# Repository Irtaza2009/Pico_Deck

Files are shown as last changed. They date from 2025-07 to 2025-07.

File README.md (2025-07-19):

# Pico Deck + USB Rubber Ducky 

### **A flash-drive-sized USB macropad and rubber ducky!**  



A small **flash-drive** but with *__buttonnnnsssss for shortcuts__* instead of storage!! And with a _custom **rp2040** devboard!_
And _**LEDDDsss!**_
And it can _run different scripts_ on the computer it's plugged into, like a **USB rubber ducky**!

I created this to learn how to make a devboard, how hard it is, and what modifications can be applied to it!

## Preview

| Description | Image |
|---|---|
| Schematic | 
| PCB Top Layer |  
| PCB Bottom Layer | 
| PCB 3D Render Front |  
| PCB 3D Render Back | 
| 3D Case + PCB | 

## BOM

| Component Description | Quantity | LCSC Part # | Price (USD) | LCSC Link |
|---|---|---|---|---|
| Tactile Switch SKRPACE010 | 1 | C139797 | 0.60 | [Link](https://lcsc.com/product-detail/Tactile-Switches_ALPSALPINE-SKRPACE010_C139797.html?s_z=n_C139797) |
| 100nF Ceramic Capacitor | 20 | C14663 | 0.24 | [Link](https://lcsc.com/product-detail/Multilayer-Ceramic-Capacitors-MLCC-SMD-SMT_YAGEO-CC0603KRX7R9BB104_C14663.html) |
| 10uF Ceramic Capacitor | 2 | C19702 | 0.30 | [Link](https://lcsc.com/product-detail/Multilayer-Ceramic-Capacitors-MLCC-SMD-SMT_Samsung-Electro-Mechanics-CL10A106KP8NNNC_C19702.html) |
| 14pF Ceramic Capacitor | 2 | C5360816 | 0.30 | [Link](https://lcsc.com/product-detail/Multilayer-Ceramic-Capacitors-MLCC-SMD-SMT_CCTC-TCC0603COG140J500CT_C5360816.html) |
| WS2812B RGB LED (2020) | 8 | C965555 | 4.00 | [Link](https://lcsc.com/product-detail/RGB-LEDs-Built-in-IC_Worldsemi-WS2812B-2020_C965555.html) |
| 27Ω Resistor | 2 | C137753 | 0.12 | [Link](https://lcsc.com/product-detail/Chip-Resistor-Surface-Mount_YAGEO-RC0603FR-0727RL_C137753.html) |
| 10kΩ Resistor | 2 | C98220 | 0.11 | [Link](https://lcsc.com/product-detail/Chip-Resistor-Surface-Mount_YAGEO-RC0603FR-0710KL_C98220.html) |
| 1kΩ Resistor | 1 | C22548 | 0.11 | [Link](https://lcsc.com/product-detail/Chip-Resistor-Surface-Mount_YAGEO-RC0603FR-071KL_C22548.html) |
| Tactile Switch B3U-1000P | 1 | C231329 | 2.00 | [Link](https://lcsc.com/product-detail/Tactile-Switches_OMRON-B3U-1000P_C231329.html) |
| Tactile Switch TS-1002S-05026C | 4 | C455110 | 1.00 | [Link](https://lcsc.com/product-detail/Tactile-Switches_XUNPU-TS-1002S-05026C_C455110.html) |
| 4-pin Header B-2100S04P-A110 | 1 | C124378 | 0.41 | [Link](https://lcsc.com/product-detail/Pin-Headers_Ckmtw-Shenzhen-Cankemeng-B-2100S04P-A110_C124378.html) |
| RP2040 Microcontroller | 1 | C2040 | 6.00 | [Link](https://lcsc.com/product-detail/Microcontrollers-MCU-MPU-SOC_Raspberry-Pi-RP2040_C2040.html) |
| LDO Regulator AP2112K-3.3TRG1 | 1 | C51118 | 1.00 | [Link](https://lcsc.com/product-detail/Voltage-Regulators-Linear-Low-Drop-Out-LDO-Regulators_DIODES-AP2112K-3-3TRG1_C51118.html) |
| Flash Memory W25Q128JWPIQ | 1 | C2689660 | 5.80 | [Link](https://lcsc.com/product-detail/NOR-FLASH_Winbond-W25Q128JWPIQ_C2689660.html) |
| USB-A Port AM90 | 1 | C404965 | 0.62 | [Link](https://lcsc.com/product-detail/USB-Connectors_SHOU-HAN-AM90_C404965.html) |
| 12MHz Crystal TAXM12M4RFBCCT2T | 1 | C133337 | 0.51 | [Link](https://lcsc.com/product-detail/Crystals_Yajingxin-TAXM12M4RFBCCT2T_C133337.html) |
| PCB | 5 | JLCPCB | 2.00 | N/A |
| PCBA | 5 | JLCPCB | 130.00 | N/A |
| Shipping | 5 | JLCPCB | 32.00 | N/A |

**PCBA is expensive:**



Subtotal (excluding PCBA): US$25

Estimated cost (PCBA, including parts and PCB): US$150 (with a coupon!)

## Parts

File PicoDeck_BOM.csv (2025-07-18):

No. | Quantity | Comment | Designator | Footprint | Value | Manufacturer Part | Manufacturer | Supplier Part | Supplier | Price ($) | Link
1 | 1 | SKRPACE010 | BOOT | KEY-SMD_4P-L4.2-W3.2-P2.20-LS4.6 |  | SKRPACE010 | ALPSALPINE(阿尔卑斯阿尔派) | C139797 | LCSC | 0.6 | https://lcsc.com/product-detail/Tactile-Switches_ALPSALPINE-SKRPACE010_C139797.html?s_z=n_C139797
2 | 20 | 100nF | C1,C2,C3,C4,C5,C6,C7,C8,C9,C10,C11,C14,C15,C16,C17,C18,C19,C20,C21,C22 | C0603 | 100nF | CC0603KRX7R9BB104 | YAGEO(国巨) | C14663 | LCSC | 0.24 | https://lcsc.com/product-detail/Multilayer-Ceramic-Capacitors-MLCC-SMD-SMT_YAGEO-CC0603KRX7R9BB104_C14663.html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
3 | 2 | 10uF | C12,C13 | C0603 | 10uF | CL10A106KP8NNNC | SAMSUNG(三星) | C19702 | LCSC | 0.3 | https://lcsc.com/product-detail/Multilayer-Ceramic-Capacitors-MLCC-SMD-SMT_Samsung-Electro-Mechanics-CL10A106KP8NNNC_C19702.html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
4 | 2 | 14pF | C23,C24 | C0603 | 14pF | TCC0603COG140J500CT | CCTC(三环) | C5360816 | LCSC | 0.3 | https://lcsc.com/product-detail/Multilayer-Ceramic-Capacitors-MLCC-SMD-SMT_CCTC-TCC0603COG140J500CT_C5360816.html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
5 | 8 | WS2812B-2020 | LED1,LED2,LED3,LED4,LED5,LED6,LED7,LED8 | LED-SMD_4P-L2.0-W2.0-TL_WS2812B-2020 |  | WS2812B-2020 | worldsemi | C965555 | LCSC | 4.0 | https://lcsc.com/product-detail/RGB-LEDs-Built-in-IC_Worldsemi-WS2812B-2020_C965555.html?s_z=n_C965555
6 | 2 | 27Ω | R1,R2 | R0603 | 27Ω | RC0603FR-0727RL | YAGEO(国巨) | C137753 | LCSC | 0.12 | https://lcsc.com/product-detail/Chip-Resistor-Surface-Mount_YAGEO-RC0603FR-0727RL_C137753.html?s_z=n_C137753
7 | 2 | 10kΩ | R3,R5 | R0603 | 10kΩ | RC0603FR-0710KL | YAGEO(国巨) | C98220 | LCSC | 0.11 | https://lcsc.com/product-detail/Chip-Resistor-Surface-Mount_YAGEO-RC0603FR-0710KL_C98220.html?s_z=n_C98220
8 | 1 | 1kΩ | R4 | R0603 | 1kΩ | RC0603FR-071KL | YAGEO(国巨) | C22548 | LCSC | 0.11 | https://lcsc.com/product-detail/Chip-Resistor-Surface-Mount_YAGEO-RC0603FR-071KL_C22548.html?s_z=n_C22548
9 | 1 | B3U-1000P | RESET_KEY1 | KEY-SMD_B3U-1000PM |  | B3U-1000P | OMRON(欧姆龙) | C231329 | LCSC | 2.0 | https://lcsc.com/product-detail/Tactile-Switches_OMRON-B3U-1000P_C231329.html?s_z=n_B3U-1000P%2509
10 | 4 | TS-1002S-05026C | SW1,SW2,SW3,SW4 | KEY-SMD_4P-L6.0-W6.0-P4.50-LS9.0 |  | TS-1002S-05026C | XUNPU(讯普) | C455110 | LCSC | 1.0 | https://lcsc.com/product-detail/Tactile-Switches_XUNPU-TS-1002S-05026C_C455110.html?s_z=n_C455110
11 | 1 | B-2100S04P-A110 | SWD1 | HDR-TH_4P-P2.54-V-M |  | B-2100S04P-A110 | Ckmtw(灿科盟) | C124378 | LCSC | 0.41 | https://lcsc.com/product-detail/Pin-Headers_Ckmtw-Shenzhen-Cankemeng-B-2100S04P-A110_C124378.html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
12 | 1 | RP2040 | U1 | LQFN-56_L7.0-W7.0-P0.4-EP |  | RP2040 | Raspberry Pi(树莓派) | C2040 | LCSC | 6.0 | https://lcsc.com/product-detail/Microcontrollers-MCU-MPU-SOC_Raspberry-Pi-RP2040_C2040.html?s_z=n_C2040
13 | 1 | AP2112K-3.3TRG1 | U6 | SOT-25-5_L2.9-W1.6-P0.95-LS2.8-BL |  | AP2112K-3.3TRG1 | DIODES(美台) | C51118 | LCSC | 1.0 | https://lcsc.com/product-detail/Voltage-Regulators-Linear-Low-Drop-Out-LDO-Regulators_DIODES-AP2112K-3-3TRG1_C51118.html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
14 | 1 | W25Q128JWPIQ | U7 | WSON-8_L6.0-W5.0-P1.27-BL-EP |  | W25Q128JWPIQ | Winbond(华邦) | C2689660 | LCSC | 5.8 | https://lcsc.com/product-detail/NOR-FLASH_Winbond-W25Q128JWPIQ_C2689660.html?s_z=n_C2689660
15 | 1 | AM90 | USB3 | USB-AM-TH_AM90 |  | AM90 | SHOU HAN(首韩) | C404965 | LCSC | 0.62 | https://lcsc.com/product-detail/USB-Connectors_SHOU-HAN-AM90_C404965.html?s_z=n_C404965
16 | 1 | 12MHz | X1 | CRYSTAL-SMD_4P-L3.2-W2.5-BL | 12MHz | TAXM12M4RFBCCT2T | YJX(雅晶鑫) | C133337 | LCSC | 0.51 | https://lcsc.com/product-detail/Crystals_Yajingxin-TAXM12M4RFBCCT2T_C133337.html?s_z=n_C133337

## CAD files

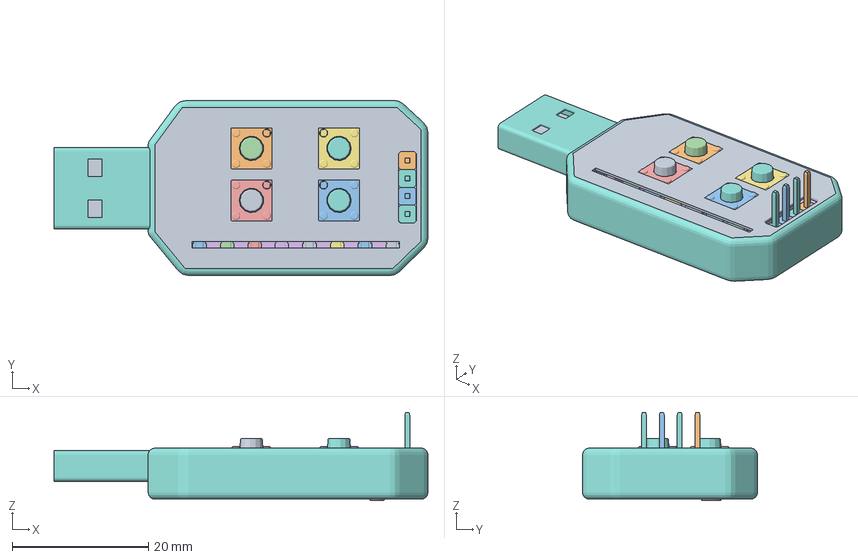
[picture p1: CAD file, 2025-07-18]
CAD/Pico_Deck_Full_With_PCB.3mf
54.8 x 25.7 x 12.9 mm
Imported_11
Imported_91
Imported_43
Imported_04
Imported_06
Imported_07
Imported_05
Imported_44
Imported_38
Imported_08
Imported_09
Imported_87
Imported_45
Imported_10
Imported_02
Imported_20
Imported_14
Imported_105
Imported_19
Imported_22
Imported_32
Imported_17
Imported_23
Imported_13
Imported_72
Imported_26
Imported_27
Imported_01
Imported_29
Imported_74
Imported_25
Imported_46
Imported_15
Imported_31
Imported_51
Imported_30
Imported_18
Imported_116
Imported_34
Imported_95
Imported_21
Imported_36
Imported_39
Imported_42
Imported_93
Imported_54
Imported_37
Imported_48
Imported_24
Imported_65
Imported_49
Imported_50
Imported_28
Imported_69
Imported_85
Imported_53
Imported_76
Imported_55
Imported_56
Imported_47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

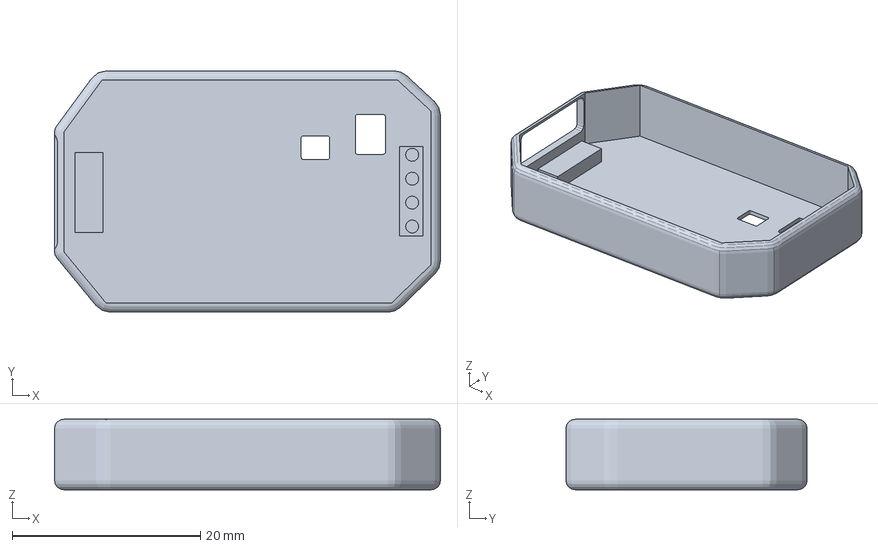
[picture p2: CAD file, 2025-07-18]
CAD/Pico_Deck_Bottom.3mf
41.0 x 25.7 x 7.50 mm

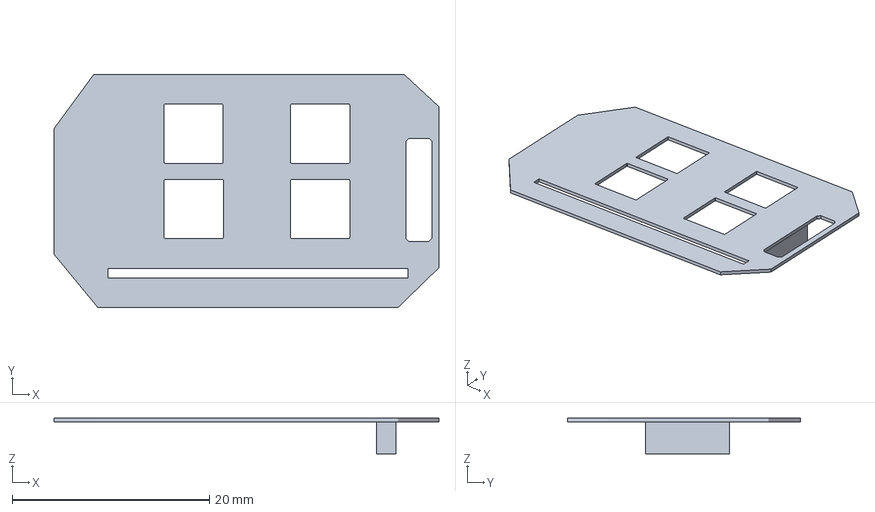
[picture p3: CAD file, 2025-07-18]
CAD/Pico_Deck_Top.3mf
39.0 x 23.7 x 3.60 mm

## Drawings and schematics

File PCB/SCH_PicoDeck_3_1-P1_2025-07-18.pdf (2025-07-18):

# QSPI_SD3 51 DVDD ⁵⁰

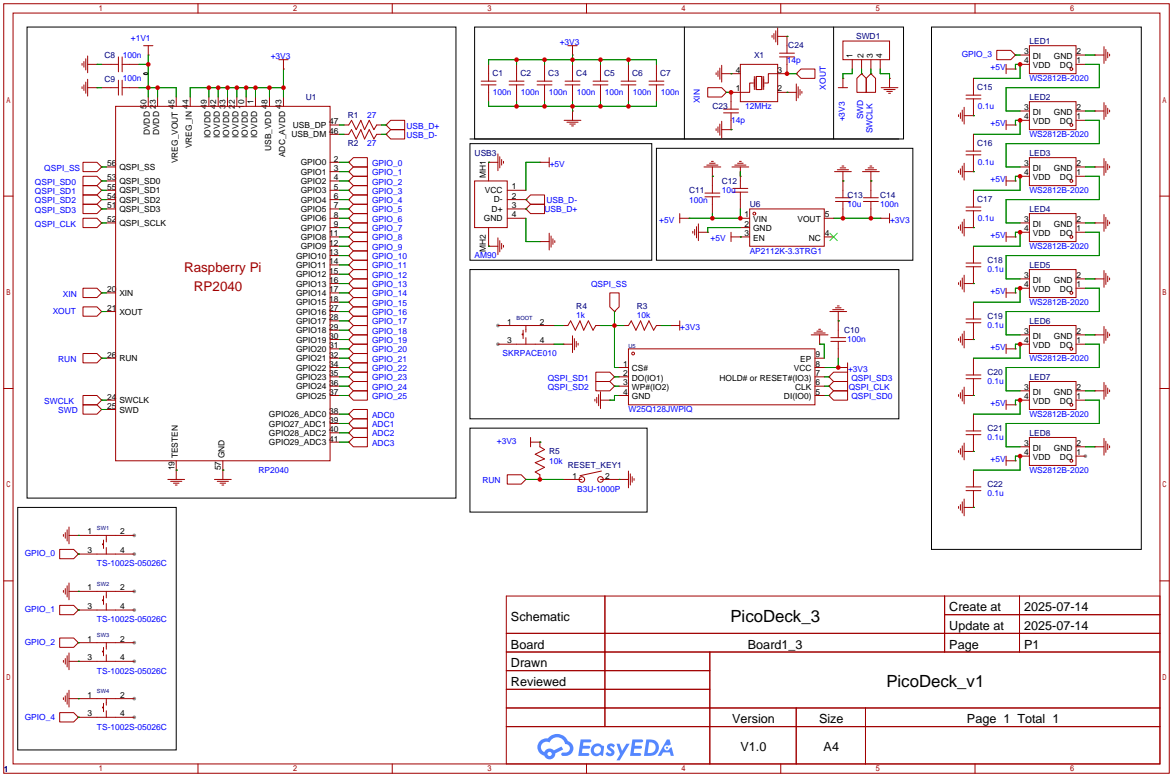
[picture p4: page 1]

Schematic | PicoDeck_3 | Create at | 2025-07-14

Update at | 2025-07-14

Board | Board1_3 | Page | P1
Drawn | | PicoDeck_v1
Reviewed

Version | Size | Page 1 Total 1
V1.0 | A4

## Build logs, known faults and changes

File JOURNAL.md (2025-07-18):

---
title: "Pico Deck"
author: "@Irtaza"
description: "A small flash drive, but with buttons (for shortcuts) and LEDs instead of storage!! With a custom RP2040 devboard! And with USB rubber ducky capabilities!"
created_at: "2025-07-11"
---

----

### Total Time Spent: ~23 hours!!

## July 11th: Completed Schematic + PCB design!

Started out by researching some **RP2040 devboard guides**. Like this [one](https://www.circuitstate.com/projects/mitayi-pico-rp2040-r0-5-open-source-microcontroller-development-board-schematic-pcb-and-assembly/)!

I decided to give **EasyEDA Pro** for the first time for this project! Usually, I use **KiCAD**!

Then I looked at different schematics and completed the RP2040 devboard part of my schematic! Instead of a USB-C or microUSB female port, I instead used a **USB-A port** with the RP2040, because that fulfils my purpose! All of the components I used are SMD! For the flash, I used **128Mbit W25Q128JWPIQ**. And the 3.3V voltage regulator I used was the **AMS1117-3.3**! 

After the devboard was completed, I added **4 tactile switches**. They will serve as the _keys_! And for the lights, at first I was going for normal LEDs, but then realised I could use something like the **WS2812B** for _cool animations_ or _effects_, so I went with those! WS2812B operate at 3.7-5.3V, so I powered them directly from the USB_VBUS instead of the RP2040. I added _8 WS2812B_, and they can _all be controlled by a single RP2040 GPIO pin!_ Their main advantage is that they can be chained, and then the Neopixel library can be used for easy programming!

After that, I went to the PCB tab, updated all the components, and placed them in a nice layout. I tried to place all the components close that I had read online had to be placed close to a part. I placed all the resistors, capacitors, and every component except for the WS2812B and buttons on the bottom layer, and the buttons and the WS2812B on the top layer! Then I made a nicely styled outline for the board! Now the only thing left is **routing** (_auto-routing isn't working, I might have to rearrange some components_)!
<details>
<summary>
<b>Schematic:</b>
</summary>
<p>
SCH_PicoDeck
</p>
</details>

<details>
<summary>
<b>PCB:</b>
</summary>
<p>
PicoDeck_PCB_Top_LayerPicoDeck_PCB_Bottom_Layer
</p>
</details>

**Total time spent: 7 hours**

## July 12th: Finished Schematic + PCB design and Firmware!

I started off by moving around some components and then autorouting again. It did not work. I had to move around components, change the board outline, and manually route some components myself. After 8 tries, auto-routing finally managed to route everything except for 2 pads, which I manually routed. All of this auto routing took a lot of time (>5-10minutes every time), so I also started working on the firmware side-by-side!

I used CircuitPython for the firmware because I have used it for past projects like [Hackamon](https://github.com/Irtaza2009/Hackamon).

I had 4 buttons, and using the adafruit_hid library, I mapped the buttons to copy, paste, undo, and redo! Then I used the neopixel library to make some animations using the WS2812Bs!! At boot, the LEDs will light up a red-to-green gradient left to right, and then turn green! And upon any button press, they will play a blue wipe animation, and then return to green!

Once the basic firmware was done, I went back to my PCB and made a new, improved outline and made sure it was symmetrical! Finally, I used [this checklist](https://libsharedobject.so/howsmypcb.html) to make sure my PCB was alright, and it was not :(. I was using vias on the USB data lines, and also, the data lines were not of equal length. So I removed all the routes, did the USB data line manually, and then auto-routed again! This time, it left 6 pins un-routed, which I had to move components, traces, etc., to fix. But finally, I got 0 errors on the DRC! I added ground planes on both layers for good measure, and finally, my PCB design was finished! 

Then I posted the Schematic and PCB design on [r/PrintedCircuitBoard](https://www.reddit.com/r/PrintedCircuitBoard/) for a review!

<details>
<summary>
<b>Schematic:</b>
</summary>
<p>
SCH_PicoDeck_1_1-P1_2025-07-13 (2)
</p>
</details>

<details>
<summary>
<b>PCB:</b>
</summary>
<p>
PCB Top Layer
PCB Bottom Layer
</p>
</details>

**Total time spent: 6 hours**

## July 13th: Review + Schematic and PCB Changes 

I received some valuable feedback from my Reddit post, which made me change the voltage regulator from the AMS1117-3.3 to the AP2112K-3.3. I also fixed several pins on the schematic and added more vias to the ground planes. I attempted to switch to a four-layer design but found the routing to be challenging, so I decided to revert to two layers. I believe the PCB can be finalised now!

**Total time spent: 2 hours**

## July 17th: 3D Case

I finally remembered to charge my Apple Pencil and reinstall Shapr3D, so I started working on the case. First, I imported the 3D model of the PCB from EasyEDA. Then, I sketched an outline around it, offset it, and extruded the shape. After that, I created the sides and the top plate. 

Next, I added two holes on the bottom side for the boot and reset buttons, along with four holes on the top side for the other buttons. I also included a large rectangle for the debugging headers and a line for the LEDs. To enhance stability, I added spacers to both the bottom and top pieces. Finally, I filleted the edges to give the design a more professional look!

I exported the models as .3mf, because .step is only for the PRO version!

3D Case Top
3D Case Bottom

**Total time spent: 2.5 hours**

## July 18th: USB Rubber Ducky Update + BOM  

I just realised that this device can be transformed into a perfect rubber ducky! A USB rubber ducky is a device that replicates keyboard keystrokes at a much higher speed.

I immediately got to work creating a CircuitPython script that runs different scripts on the computer depending on which button is pressed. The script can execute one of four payloads based on the button pressed. I reused the light and gradient animations from the Macropad script! Additionally, I created two payloads, one for Windows and one for Mac, that will open the terminal and display the message, "Hello from the rubber ducky!"!!

Then I started working on submitting and making the BOM, and had to go through device standardisation on EasyEDA, and that took a lot of time and revisions!

After that was done, I exported the BOM and started adding links and prices for each of the parts!

**Total time spent: 5.5 hours**

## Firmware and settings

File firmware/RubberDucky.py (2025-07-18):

import board
import digitalio
import neopixel
import time
import usb_hid

from adafruit_hid.keyboard import Keyboard
from adafruit_hid.keycode import Keycode
from adafruit_hid.keyboard_layout_us import KeyboardLayoutUS

# Configuration
NUM_LEDS = 8
LED_PIN = board.GP3
BRIGHTNESS = 0.3
PAYLOAD_FILES = ["payload1.txt", "payload2.txt", "payload3.txt", "payload4.txt"]
BUTTON_PINS = [board.GP0, board.GP1, board.GP2, board.GP4]

# Setup
leds = neopixel.NeoPixel(LED_PIN, NUM_LEDS, brightness=BRIGHTNESS, auto_write=False)
buttons = []

for pin in BUTTON_PINS:
    btn = digitalio.DigitalInOut(pin)
    btn.direction = digitalio.Direction.INPUT
    btn.pull = digitalio.Pull.UP
    buttons.append(btn)

keyboard = Keyboard(usb_hid.devices)
layout = KeyboardLayoutUS(keyboard)

def gradient_animation():
    colors = [
        (255, 0, 0), (255, 64, 0), (255, 128, 0), (255, 192, 0),
        (255, 255, 0), (128, 255, 0), (64, 255, 0), (0, 255, 0)
    ]
    for i in range(NUM_LEDS):
        leds[i] = colors[i]
        leds.show()
        time.sleep(0.05)

def set_all(color):
    for i in range(NUM_LEDS):
        leds[i] = color
    leds.show()

def press_animation():
    for i in range(NUM_LEDS):
        leds[i] = (255, 0, 128)
        leds.show()
        time.sleep(0.01)
    set_all((0, 255, 0))

def run_payload(filename):
    try:
        with open(filename, "r") as f:
            for line in f:
                line = line.strip()
                if not line:
                    continue
                elif line.startswith("DELAY "):
                    time.sleep(int(line.split()[1]) / 1000)
                else:
                    layout.write(line)
                    keyboard.send(Keycode.ENTER)
                    time.sleep(0.05)
    except Exception as e:
        print(f"Error running {filename}: {e}")

# Startup
gradient_animation()
time.sleep(0.2)
set_all((0, 255, 0))

# Main Loop
while True:
    for i, btn in enumerate(buttons):
        if not btn.value:
            press_animation()
            run_payload(PAYLOAD_FILES[i])
            while not btn.value:
                time.sleep(0.01)
    time.sleep(0.01)

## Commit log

2025-07-18 Added CAD files!
    [Pico_Deck_Bottom.3mf, Pico_Deck_Full_With_PCB.3mf, Pico_Deck_Top.3mf]
2025-07-18 Added BOM + gerbers
    [BOM_PicoDeck.csv, PickAndPlace_PCB1_4_2025-07-18.xlsx, PicoDeck_BOM.csv]
